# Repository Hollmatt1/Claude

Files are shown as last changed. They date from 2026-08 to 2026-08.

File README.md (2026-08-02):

# Manga Cargo Cube — A1 mini

A **true 264 mm cube** — same on every axis — printed in 16 parts that lock
together with no glue, no screws and no supports.

The cube is **solid but for one book pocket**: a single wide slot milled into
the block, opening on the front face. Ten volumes slide in pressed together,
snug on all four sides, standing 3 mm proud so you can grip a spine. No
dividers, so nothing draws a line across the front. No open bay, no lid to
lift.

The exterior copies **crate C** from the reference art, in two tones you get
from ordinary single-colour prints:

- The **whole cap tier is the light lid**, so the tier split and the colour
  split are the same line — print the four `cap_*` parts in cream.
- The **corner posts are separate slide-on covers**, so they are cream too and
  run the full height of the body, as on the reference. Each drops over its
  rebated corner and is then trapped by the cap landing on it.
- The **body** is yellow: four `base_*` octants carrying the recessed field
  panels, each with a latch plate, a wide louver recess and small label
  placards.

The posts go **46 mm deep on the side faces** and 31 mm on the front. Only the
front is capped by the pocket, and only the front needed to be.

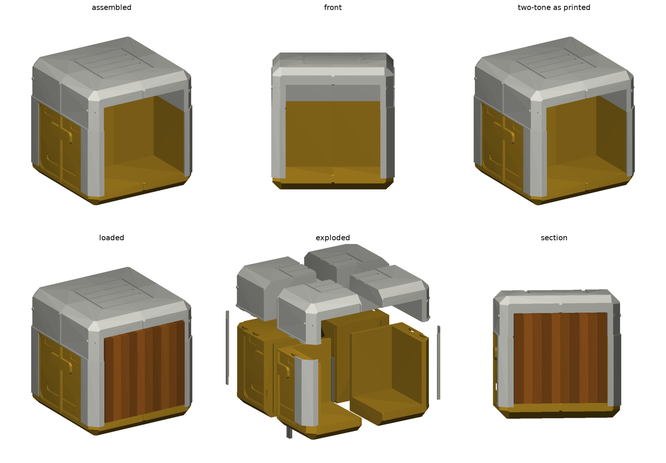
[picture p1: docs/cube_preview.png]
preview


```
python3 -m pip install -r requirements.txt
python3 src/manga_cube.py --out stl          # writes all 12 STLs
PYTHONPATH=src python3 src/verify_cube.py    # parts, fit, locks, printability
PYTHONPATH=src python3 src/render_cube.py --out docs
```

## Why 12 parts

A 216 mm cube has no piece that fits the A1 mini's 180 mm plate whole. Any
2-way split of a cube over 180 mm leaves at least one piece carrying a
full-width cross-section, and the largest square that fits inside a 180 mm cube
is only ~191 mm — so **all three axes have to be split**. 2 × 2 × 2 is the
coarsest split that works: eight 108 mm octants, plus four spline keys.

264 mm is set by capacity, not by the book: ten spines pressed together are
202 mm across, and the pocket needs a solid margin either side wide enough to
carry the cap's dovetail channels. At 224 mm that margin falls to 11 mm and the
lock has nowhere to live.

## What the pocket still costs

The front face is mostly pocket — ten volumes are 202 mm of a 264 mm face — so
the crate styling is carried by the other three faces plus the cap and foot
bands, and the front post arms are held to 31 mm. Everything else the reference
has, this has.

## How it locks

The hard part is that **four pieces in a closed ring cannot all use the same
sliding joint** — the last one would have to slide two directions at once. So
the two tiers lock differently:

**Lower ring** — the four base octants butt together, then four dovetail
spline keys drop down the vertical seams. Each key is a *bowtie* in section,
widest at both roots and pinched at the seam, so neither octant can pull away
sideways. Once the cap is on, the keys are trapped and cannot back out.

**Cap** — each upper octant locks to the body **on its own**: set it down 8 mm
forward, lower it so two dovetail tenons drop into their pockets, then slide it
back. The channels are blind, so it stops exactly flush. Because no cap piece
depends on its neighbours, the ring-of-four problem never arises.

`verify_cube.py` proves the mechanism rather than assuming it: for every cap
octant it sweeps the descent and the slide for collisions, confirms the blind
channel stops it (43 mm³ of interference if pushed 1 mm past flush), and
confirms it cannot be lifted — 0.60 mm of play before the dovetail bites. It
also pulls a base octant sideways and checks it fouls its key.

## Assembly

1. Butt the four `base_*` octants together on a flat surface.
2. Drop `key_1`–`key_4` down the vertical seams. The lower ring is now locked
   laterally.
3. Drop each `post_*` cover down over its rebated corner.
4. For each `cap_*` octant: set it on its quarter 8 mm forward, lower it, slide
   it back until it stops. It is now locked down, and the keys and post covers
   beneath it are captive.

## Specification

| | |
| --- | --- |
| Assembled | 264 × 264 × 264 mm, true cube |
| Parts | 8 octants (176 mm base, 88 mm cap) + 4 post covers + 4 keys |
| Capacity | 10 volumes, pressed together in one pocket |
| Pocket | 202 × 124 × 194 mm — 2 mm slack over 10 spines, books 3 mm proud |
| Floor / ceiling | 34 / 36 mm |
| Lid line / tier split | 176 mm, two-thirds height |
| Cap lock | 8 dovetail tenons, 8 mm travel, blind channels, 0.20 mm fit |
| Material | 10183 cm³ solid across all parts |

## Printing

No supports anywhere. All relief is cut into the envelope, openings flare 45°,
and both wide recesses are narrow grooves instead, so nothing bridges more than
10 mm. `verify_cube.py` asserts this against each part in its own orientation.

- **Supports:** off · **Layer:** 0.2 mm · **Walls:** 3 · **Infill:** 10–15%
- **Orientation:** as exported. Base octants sit floor-down, cap octants are
  already flipped crown-down, keys stand on end.
- **Filament: roughly 2.0–2.4 kg**, and a long queue of 12 large prints. This
  is the real cost of ten volumes: capacity set the cube size, and volume goes
  as the cube of it. A solid cube is mostly infill rather than plastic, so this
  sits well under the 10135 cm³ solid figure — but it is an estimate, so slice
  it for real numbers. **`N_BOOKS` is the knob**: dropping to 6 returns the
  cube to 224 mm and about 1.4 kg.

If the dovetails or keys are tight on your printer, raise `FIT`; if they
rattle, lower it. 0.20 mm per side is the starting point.

## Changing it

Everything lives in the `PARAMETERS` block of `src/manga_cube.py`.

- `N_BOOKS` — capacity, and the thing that sets `SIDE`
- `SIDE` — the cube. Below ~213 mm the book no longer fits standing
- `POST_FRONT` / `POST_SIDE`, `BASE_H`, `PLATE`, `VENT`, `PLACARD` — the
  crate C exterior. Only `POST_FRONT` is capped by the pocket
- `COVER_T` / `COVER_FIT` — the slide-on corner post covers
- `N_BOOKS`, `SLOT_*`, `BOOK_*` — the pocket and the media it is cut for
- `EDGE_CH` / `CORNER_CH`, `PANEL_R`, `EMBLEM_*`, `SEAM_Z` — the loot-box look:
  bevel size, panel corner radius, the disc plate, and the lid line
- `VOID_*` — the hidden chambers behind the slot backs
- `RELIEF_FRAME` / `_BEVEL` / `_FIELD` / `_VENT` — the four relief planes.
  `RELIEF_VENT` must stay well clear of `WALL` or the louvers cut through
- `TRAVEL`, `DT_*`, `KEY_*`, `FIT` — the locks

Four rules the code depends on:

- All exterior relief is **cut from** the envelope, never added to a smaller
  body, so no detailing can push a part past the plate.
- The seam straps sit at the full envelope **on purpose**: every split line
  lands under one, so a joint reads as a strap rather than a crack. The
  horizontal one doubles as the loot-box lid line.
- The post covers' arm bands must reach **past the edge chamfer**. The chamfer
  truncates the corner, so a band only as deep as the cover leaves the two
  arms meeting nowhere and the cover comes out as two loose pieces.
- `skin_side()` exists because `profile()` insets in Z as well as X and Y, so a
  plain `skin()` carries full-width slabs at the crown and base. Cutting with
  those shaves the ends; clipping them off in Z instead lands a cut plane on
  the inset profile's end face and detaches them into separate bodies.
- `cleanup()` drops hairline boolean debris. Meshes are exported **raw**:
  welding them to satisfy `is_watertight` turned point-pinches into real holes.
  `mesh_report()` counts boundary edges instead, which is the property that
  actually matters — all 12 parts have zero.
- The hidden chambers are **gabled, and split into strips**. A flat-roofed
  buried void is thousands of mm² of ceiling that no support could ever be
  removed from; and a 45° gable only closes over twice its own rise, so a
  chamber deeper than that is divided into strips that can each roof
  themselves. The upper chamber is short and deep and needs this.

## Assembly note

Loading is through the pocket only — the cap octants do come off individually
(slide one forward 8 mm and lift), but you never need to.

Earlier designs — a one-piece 178 mm cube, a two-part 178 × 178 × 205 mm crate,
a 216 mm open-bay cube, a six-slot version with dividers, and a 224 mm
six-volume cube — are in git history on this branch.

## Two-tone

Cream: the four `cap_*` octants and the four `post_*` covers.
Yellow: the four `base_*` octants.
The keys are hidden once assembled, so any colour.

That is the reference crate's scheme exactly, from single-colour prints — the
posts are separate parts precisely so the colour can reach them.

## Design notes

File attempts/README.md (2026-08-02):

# Attempts

Kept so we can go back to one, not just read a diff.

## crate_c_v1 — best yet

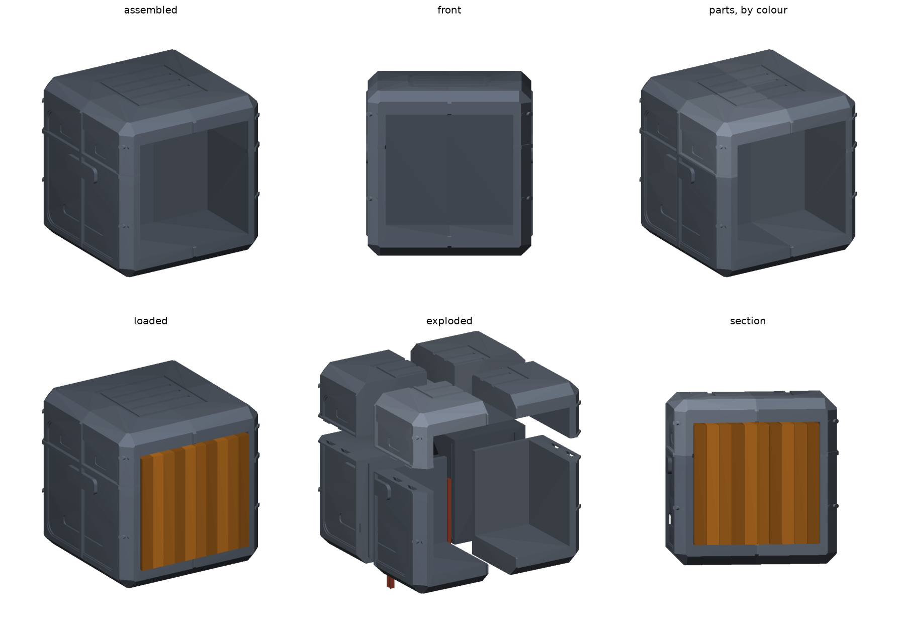
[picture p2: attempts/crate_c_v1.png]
crate_c_v1


264 mm cube, 10 volumes, 12 parts. Exterior copies crate C: light corner posts,
deep top cap band, recessed field panels, latch plate, louver, placards.

Restore with `cp attempts/crate_c_v1.py src/manga_cube.py`.

Two things it did not solve, both of which turned out to be solvable:

- **Corner posts were thin (31 mm).** Capped by the pocket margin — but only on
  the *front* face, where the pocket actually opens. The side faces have no such
  limit, so the posts can be much deeper there.
- **Two-tone could not colour the posts.** True for a tier-based colour split,
  because the posts run the full height. Not true in general: the posts can be
  separate slide-on covers, trapped by the cap.

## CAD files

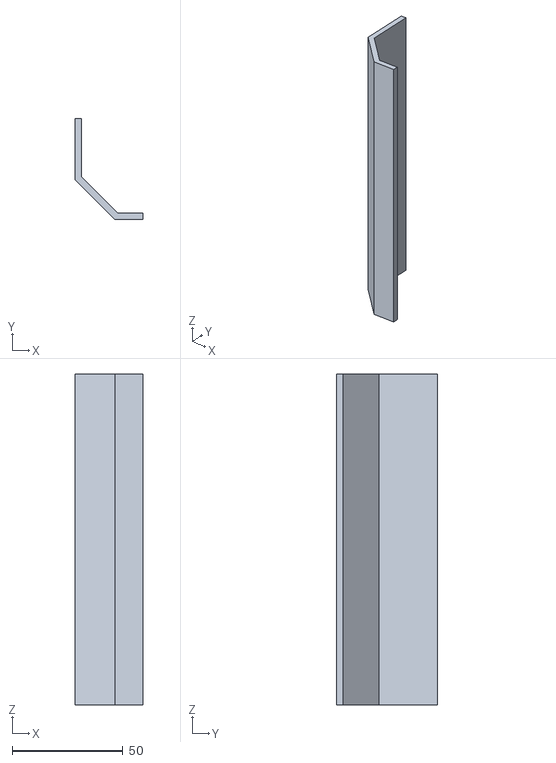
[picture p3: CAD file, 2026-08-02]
stl/cube_post_BL.stl
30.8 x 45.8 x 149.8

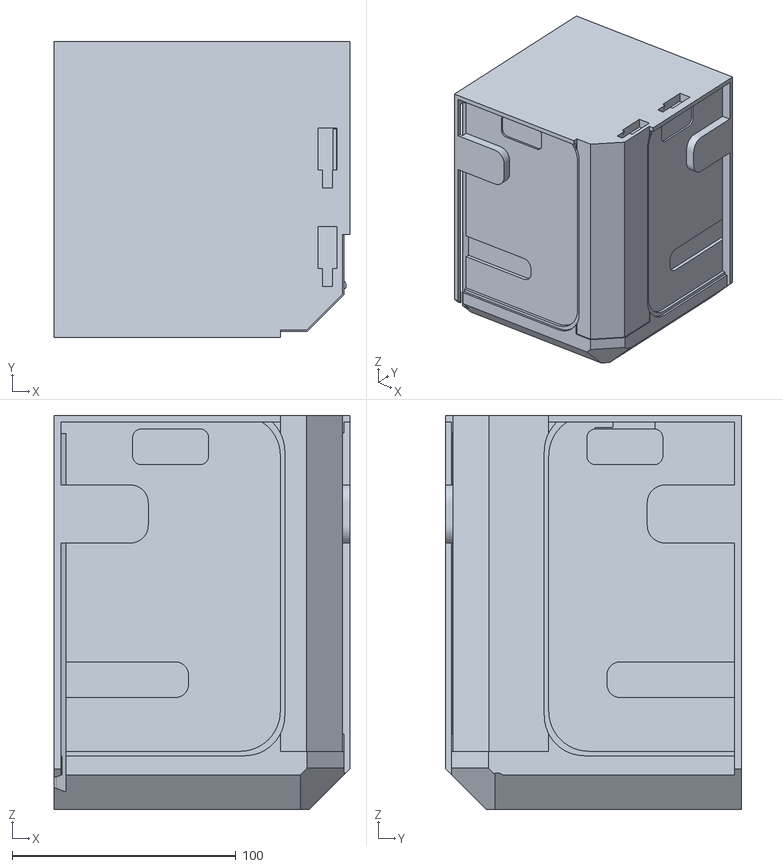
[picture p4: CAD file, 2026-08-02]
stl/cube_base_BR.stl
132.0 x 132.0 x 176.0

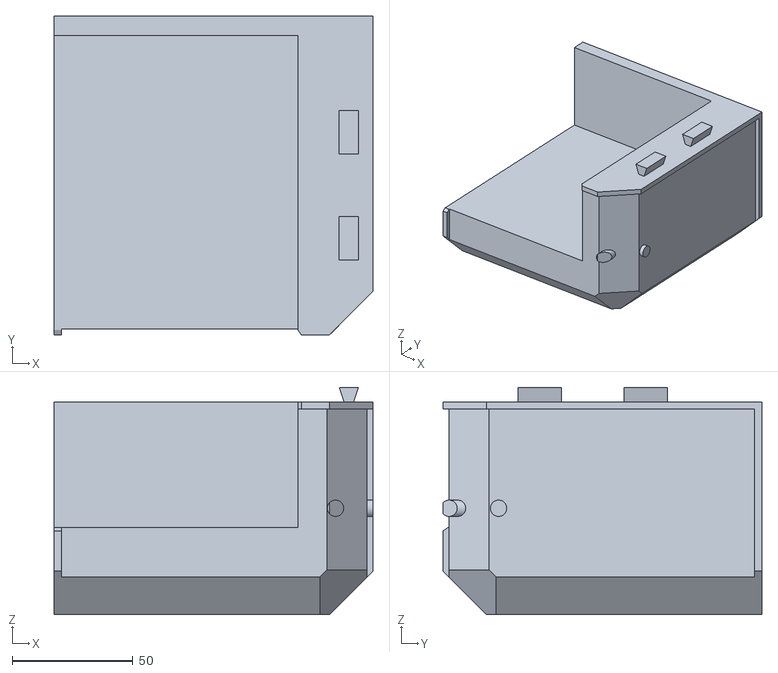
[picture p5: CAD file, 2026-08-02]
stl/cube_cap_FR.stl
132.0 x 132.0 x 94.0

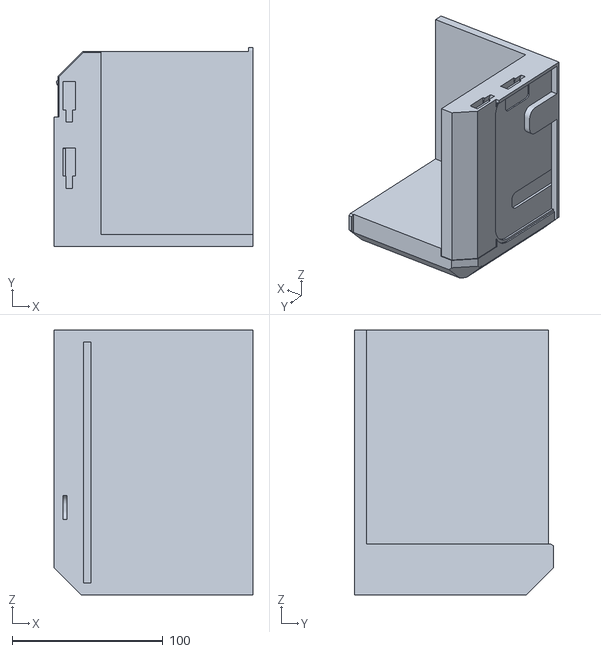
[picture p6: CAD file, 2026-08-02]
stl/cube_base_FL.stl
132.0 x 132.0 x 176.0

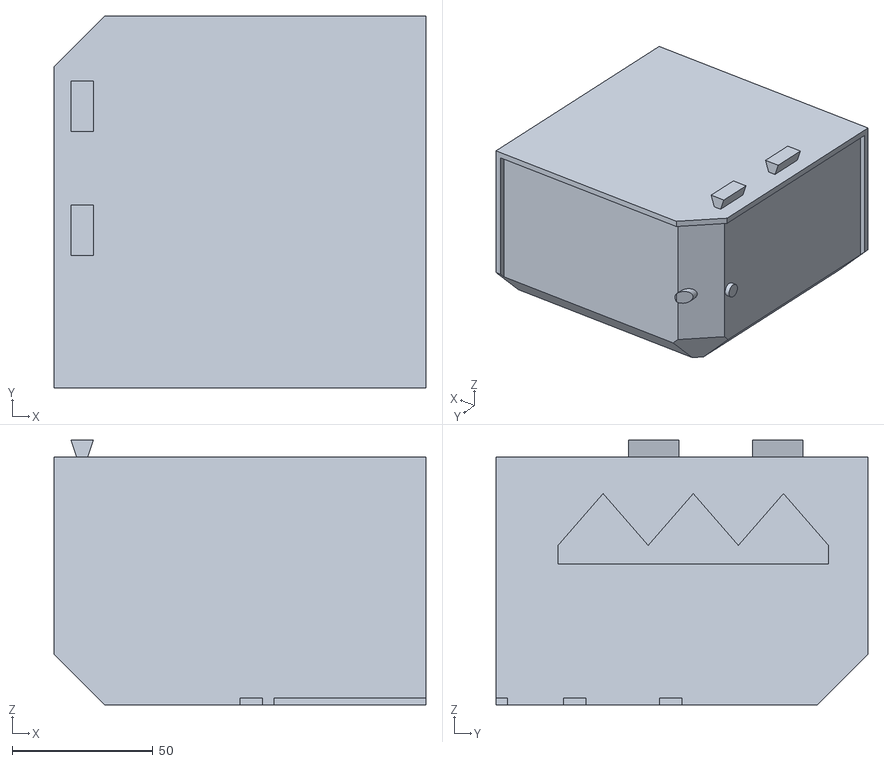
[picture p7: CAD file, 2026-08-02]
stl/cube_cap_BL.stl
132.0 x 132.0 x 94.0

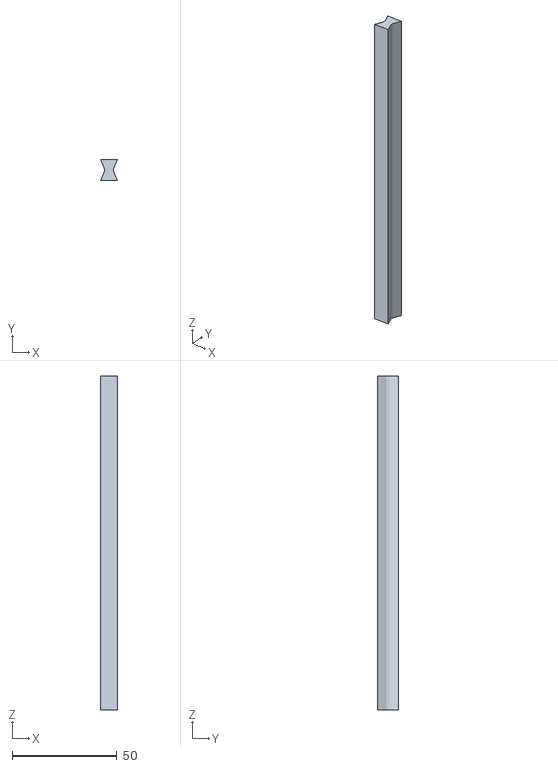
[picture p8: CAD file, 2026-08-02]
stl/cube_key_4.stl
8.00 x 10.0 x 159.6

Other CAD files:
stl/cube_post_BR.stl
stl/cube_cap_FL.stl
stl/cube_base_BL.stl
stl/cube_post_FR.stl
stl/cube_post_FL.stl
stl/cube_base_FR.stl
stl/cube_cap_BR.stl
stl/cube_key_3.stl
stl/cube_key_2.stl
stl/cube_key_1.stl

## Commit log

2026-08-01 Add parametric manga loot cube for the Bambu A1 mini
    A 178 mm bevelled cube that holds standing manga volumes, generated by CSG
    and exported as a single-piece, support-free STL.
    Because a Viz shonen volume is 190.5 mm tall and the A1 mini tops out at
    180 mm Z, a one-piece cube cannot enclose an upright volume. The design
    accepts that instead of working around it: books stand on the floor and
    their spines rise 17.5 mm proud of the top face, framed by the slot. The
    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
    [manga_loot_cube_a1mini.stl]
2026-08-01 Replace the cube with a two-part locking sci-fi cargo crate
    Reworks the model into an industrial cargo crate - corner castings, X-braced
    recessed panels, latch blocks, front hatch, banded lid - printed as a body and
    a lid that lock with a sliding dovetail.
    Corrects an earlier claim: a two-part split does NOT allow a bigger cube. Each
    part still has to fit the 180 mm plate, and any 2-way split of a 210 mm cube
    leaves a piece carrying a full 210 x 210 cross-section, which exceeds the
    ~191 mm largest square that fits inside a 180 mm cube. A true 210 mm cube needs
    eight parts. Splitting buys height only, so this is a cube-proportioned body
    plus a lid at 178 x 178 x 205 mm.
    The dovetail is shor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
    [manga_crate_body.stl, manga_crate_lid.stl, manga_loot_cube_a1mini.stl]
2026-08-02 Push the crate detailing further toward the reference concept art
    Adds the greebling that makes it read as a cargo crate rather than a bevelled
    box: octagonal recessed panels with a stepped bevel lip, louver vent banks,
    bolt heads down the corner castings, 45 degree hazard striping in the lid band,
    and deeper edge and corner faceting.
    Wall thickness goes to 10 mm so the louvers, which sink below the panel floor,
    still leave 3 mm behind them. verify_crate.py now probes behind every recess -
    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
    [manga_crate_body.stl, manga_crate_lid.stl]
2026-08-02 Make it a true 216 mm cube in 12 interlocking parts
    Allowing multiple parts removes the constraint that forced the previous
    cube-proportioned box. A 216 mm cube needs all three axes split - any 2-way
    split leaves a piece carrying a full-width cross-section, and the largest
    square that fits inside a 180 mm cube is only ~191 mm - so this is eight 108 mm
    octants plus four spline keys. 216 is the smallest cube that still swallows a
    standing 190.5 mm volume behind a 12 mm floor and a 10 mm ceiling.
    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
    [cube_base_BL.stl, cube_base_BR.stl, cube_base_FL.stl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]
2026-08-02 Make the cube solid but for the slots, and read as one object
    Replaces the open bay and front hatch with six book-shaped pockets milled into
    a solid block, one per volume, each opening on the front face. A volume slides
    in like a book into a slipcase, snug on all four sides, and sits 3 mm proud so
    the spine can be gripped. The cube grows to 224 mm so a 16 mm floor and 14 mm
    ceiling leave a real frame around the slots.
    For visual continuity, the 30 mm cover straps that chopped every face into four
    tiles are gone. Each face now carries a single octagonal panel with a full-face
    X-brace and full-width louvers running across both seams, and each split hides
    under a narrow 7 mm strap. A scribed g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
    [cube_base_BL.stl, cube_base_BR.stl, cube_base_FL.stl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]
2026-08-02 Drop the slot dividers and soften the cube toward a loot box
    The six individual pockets drew a line across the front face for every volume.
    Replaced with one wide pocket - the books are their own spacers, pressed
    together, with 2 mm of slack across all six spines and still standing 3 mm
    proud so a spine can be gripped.
    Styling moves from industrial crate toward loot box: a much larger, even soft
    bevel on every edge and corner, rounded panels in place of octagonal ones, a
    disc emblem plate, and no more louvers, X-bracing or hazard striping. The tier
    split moves from mid-height to two-thirds, so the structural seam lands exactly
    where a loot box's lid line belongs and the styling and the join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
    [cube_base_BL.stl, cube_base_BR.stl, cube_base_FL.stl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]
2026-08-02 Ten volumes, and carry the diagonal as a graphic
    Capacity goes from six to ten, which sets the cube size rather than the other
    way round: ten spines pressed together are 202 mm across, and the pocket needs
    a margin either side wide enough to carry the cap's dovetail channels. At
    224 mm that margin falls to 11 mm and the lock has nowhere to live, so the cube
    grows to 264 mm. That costs roughly 2.0-2.4 kg of filament; N_BOOKS returns it.
    A diagonal split is not printable. Wedges cut on the cube's vertical diagonals
    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
    [cube_base_BL.stl, cube_base_BR.stl, cube_base_FL.stl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]
2026-08-02 Rebuild the exterior to copy crate C from the reference
    Replaces the diagonal band and disc emblem with the reference crate's language:
    light corner posts and a deep top cap band standing at the envelope, field
    panels recessed between them, a latch plate on the centre of each face, a wide
    louver recess low on the panel, and small label placards.
    The posts cannot be as chunky as the reference. The pocket for ten volumes is
    202 mm of the 264 mm face, leaving 31 mm of margin either side, and the posts
    have to live in it. The front face is mostly pocket for the same reason, so the
    crate styling is carried by the other three faces plus the cap and foot bands.
    Design first, cutting second, as as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
    [cube_base_BL.stl, cube_base_BR.stl, cube_base_FL.stl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]
2026-08-02 Second run at the design, and both claimed limits were wrong
    Corner posts: the pocket only caps the post arm on the faces the pocket opens
    through. The side faces have no such limit, so the arms go to 46 mm there and
    stay at 31 mm on the front, which is what the reference's castings look like.
    Two-tone: a tier-based colour split genuinely cannot reach posts that run the
    full height - so the posts stop being part of the octants. They are now four
    slide-on covers that drop over a rebated corner and are trapped by the cap
    landing on them, needing no glue like everything else. Cream caps plus cream
    covers plus yellow bases is the reference crate's scheme exactly, from ordinary
    single-colour pri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
    [cube_base_BL.stl, cube_base_BR.stl, cube_base_FL.stl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]
